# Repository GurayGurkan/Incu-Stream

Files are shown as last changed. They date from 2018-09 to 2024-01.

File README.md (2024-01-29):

# Incu-stream 1.0 (initial version)
**An Open-Hardware Live-Cell Imaging System Based on Inverted Bright-field Microscopy and Automated Mechanical Scanning for Real-Time and Long-Term Imaging of Microplates in Incubator**

This repository involves:
  - **CAD files**: AutoCAD drawings for housing of Incu-stream mechanical parts
  - **Schematics and pcb**: Circuit schematics and PCB layout files of Incu-stream control electronics.
  - **Software**: Involves C codes (for Atmega328) and Python codes (for Incu-stream user interface)
  - **Videos**: Demostration of device usage and example of a real-time recording acquired during C. Elegans movement.

For suggestions and questions, please e-mail to: **~~g.gurkan@iku.edu.tr~~**} (*not valid anymore. new e-mail: **guraygurkan@istanbul.edu.tr***)

Cheers!

Guray Gurkan

* **Please cite this repo as:** 

G. Gürkan and K. Gürkan, "*Incu-Stream 1.0: An Open-Hardware Live-Cell Imaging System Based on Inverted Bright-Field Microscopy and Automated Mechanical Scanning for Real-Time and Long-Term Imaging of Microplates in Incubator*," in **IEEE Access**, vol. 7, pp. 58764-58779, 2019. **doi: 10.1109/ACCESS.2019.2914958**

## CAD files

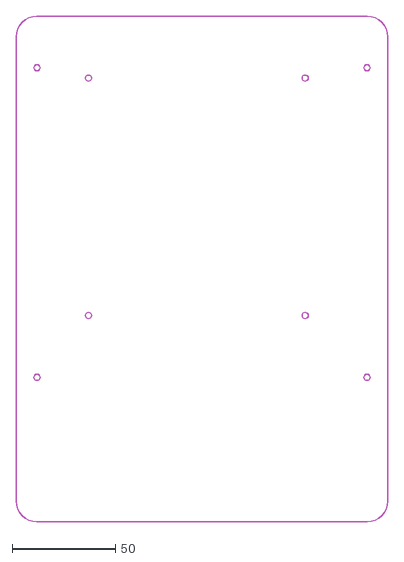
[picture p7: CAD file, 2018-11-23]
CAD_Files/IncuStreamCAD_IlluminationLayer.dxf
180.0 x 245.0

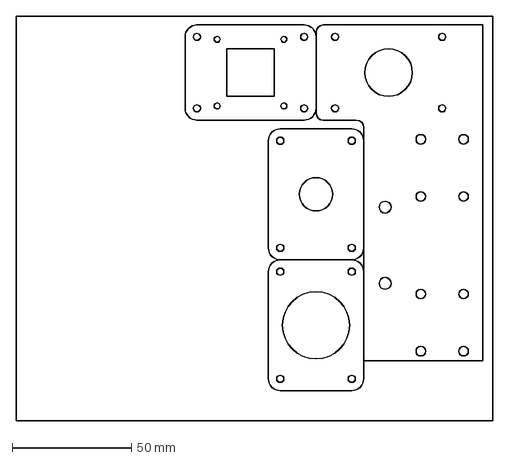
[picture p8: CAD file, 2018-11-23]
CAD_Files/IncuStreamCAD_XTray_Imager.dxf
200.0 x 170.0 mm

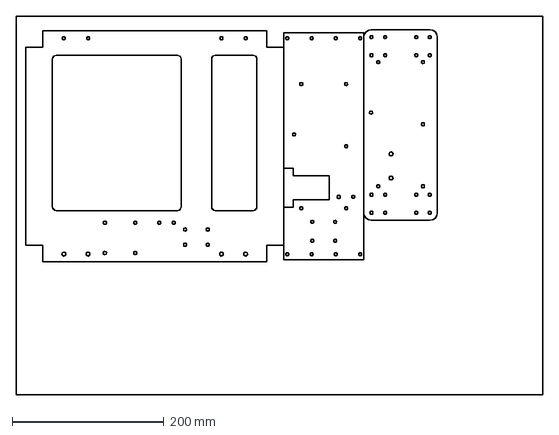
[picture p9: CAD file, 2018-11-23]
CAD_Files/IncuStreamCAD_Base_YTray.dxf
695.0 x 500.0 mm

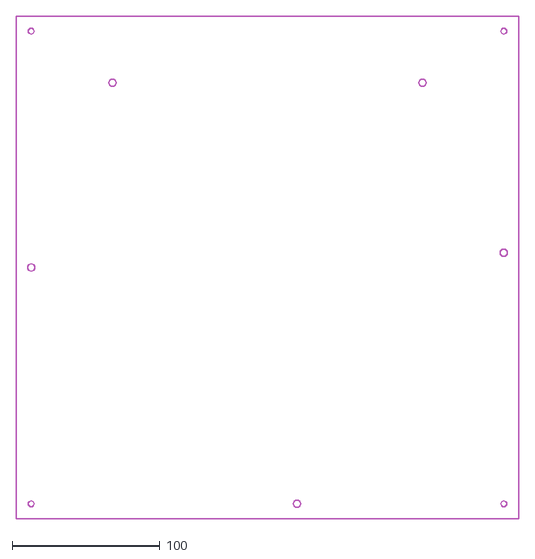
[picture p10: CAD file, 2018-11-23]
CAD_Files/IncuStreamCAD_BottomLayer.dxf
340.0 x 340.0

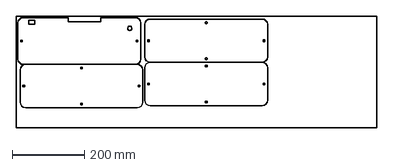
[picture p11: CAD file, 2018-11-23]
CAD_Files/IncuStreamCAD_SideLayers.dxf
1000.0 x 310.0 mm

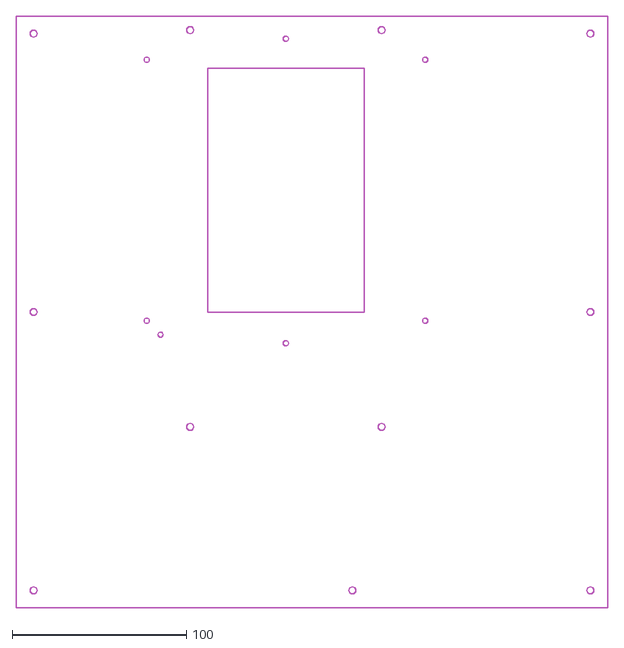
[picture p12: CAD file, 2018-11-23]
CAD_Files/IncuStreamCAD_TopLayer.dxf
340.0 x 340.0

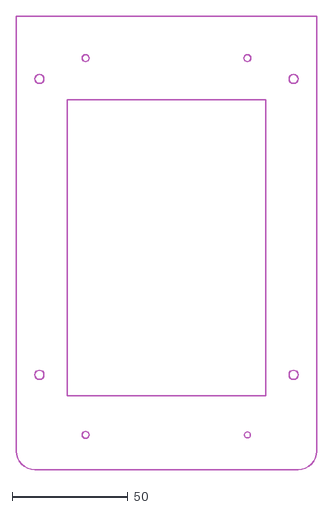
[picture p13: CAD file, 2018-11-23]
CAD_Files/IncuStreamCAD_PlateHolder.dxf
130.0 x 196.0

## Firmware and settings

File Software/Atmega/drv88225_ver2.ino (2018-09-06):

/*
Compatible with IncuStream Interface
This version has common DIR,STEP amd MODE pins for X,Y and Z (Lens) axis motors.

Developed by: Guray Gurkan, PhD
e-mail: guray_gurkan@yahoo.co.uk
*/

// 14.08.2018: Scanning Types 1,2 and 3 introduced
//  Type 1: Snake Like Scanning
//  Type 2: Single Y axis Reset, X axis bouncing
//  Type 3: Single Y axis Reset, Xaxis reset and bouncing

// StepXYZ() function changed for Long type
// Plate Offset, spacing are now in Long type
// 1/32 Microstepping is used for every movement
// XmYn command relies on "grid_selected" flag

/******************************
      DRV8825 Enable pins
******************************/
 
int Xen = 8;
int Yen = 9;
int Zen = 10;

/*****************************
      (Common) DRV8825
  Direction, Step and Mode pins
*****************************/
int XYZdir = 11; // 1->Reset Yonu, 0-> Uzaklasma
int XYZstep = 12;
int XYZSlowMode = 13;
int Positions[] = {0, 0, 0};

/*****************************
      More Externals
  X,Y Limit Switches,Buzzer, LED
*****************************/
int LEDPWM_pin = 3;
int BEEP_pin = 4;
int SWITCH_x_pin = 6;
int SWITCH_y_pin = 7 ;
int TRAY_pin = 5; // not used for current HW


/***********************************
  Well Plates vs. Steps required for TPP (1/32 Microstep)
***********************************/
unsigned long spacing[5] = {30016, 19968, 15200, 6400, 7200};
// In mm  {38, 25 , 19, ?, 9}; 

// A-1 Well Center Coordinates
unsigned long X_offset[5] = {0, 0, 49872, 0, 53664};
unsigned long Y_offset[5] = {3200, 3200, 14800, 3200, 14304};


/********************************
SUB- GRID CAMERA SHIFT steps for non-overlap
    DO NOT MODIFY!
*********************************/
unsigned long shiftX = 288;
unsigned long shiftY = 544;

 
// SUB-GRID scan row and column numbers
int rows;
int cols;

// LIVE VIEW PARAMETERS
int zstep = 320;
int zstep_fine = 40;
int xstep = 212;
int ystep = 272;

int resetsteps = 896; // in microstepping (1/32) drive mode

int deltaX;
int deltaY;

unsigned long  Xcurrent = 0;
unsigned long Ycurrent = 0;
unsigned long Zcurrent = 0;

#define SLOWMODE1 400
#define SLOWMODE2 20

int PFullDrive = 500 ; //Delay Microseconds 600 idi
int PSlowDrive = SLOWMODE2; //Delay Microseconds


/*
 *************************************
      BACKLASH CORRECTION
 *************************************
*/
byte lastdir[3] = {0, 0, 0}; // last directions
unsigned long lashes[3] = {0 , 0, 704};// 1/32 drive
int last_motor = 2;

boolean finished = false;
boolean started = false;
boolean grid_selected = false;

int plate_type;
int x_i, y_i;
int x_p, y_p;
int grid_count;
bool at_wellcenter = false;

void setup() {

  DDRB |= 0x3F;
  pinMode(BEEP_pin, OUTPUT);
  pinMode(LEDPWM_pin, OUTPUT);
  pinMode(SWITCH_x_pin, INPUT_PULLUP);//0 if at limit
  pinMode(SWITCH_y_pin, INPUT_PULLUP);

  digitalWrite(Xen, HIGH);
  digitalWrite(Yen, HIGH);
  digitalWrite(Zen, HIGH);

  delay(1000);

  delay(10);


  beep(BEEP_pin, 50, 1); // POWER ON ALERT


  // **************************************************************
  //               SETUP SERIAL and TRANSMIT DEVICE ACK
  // **************************************************************
  Serial.begin(9600);
  delay(100);

  Serial.print("INCU"); // Device ACK
  delay(100);
  beep(BEEP_pin, 400, 1);
  // **************************************************************
  //               END OF SERIAL SETUP and TRANSMIT DEVICE ACK
  // **************************************************************


  // **************************************************************
  //               SCAN DEFINITIONS: MANUAL ENTRIES
  // **************************************************************


  x_p = 0;
  y_p = 0;
  grid_count = 0;

  // **************************************************************
  //                    END OF SCAN PARAMETERS
  // **************************************************************


  // **************************************************************
  //                   LISTEN PORT and DETERMINE Plate-Type
  //            SETUP respect to input: "P" + id
  //  id=0, 6 Well
  //  id=1, 12 Well
  //  id=2, 24 Well
  //  id=3, 48 Well
  //  id=4, 96 Well
  // **************************************************************

  String sub = "";
  char val;
  while (!started)
  {
    if (wait_byte() == 'P')
    {
      val = wait_byte();
      if (isDigit(val))
      {
        sub += (char)val;
        plate_type = sub.toInt();
        sub = "";
        Serial.print("O");
        started = true;
        beep(BEEP_pin, 50, 1);

      }
    }
  }
  reset2origin(0);
  reset2origin(1);
  digitalWrite(LEDPWM_pin, 1);
  delay(1000);
  digitalWrite(LEDPWM_pin, 0);
  delay(1000);
  digitalWrite(LEDPWM_pin, 1);
  delay(1000);
  digitalWrite(LEDPWM_pin, 0);
  delay(1000);
  digitalWrite(LEDPWM_pin, 1);

}

void loop() {

  int task;
  if (!finished) {

    task = decodeMove();
    if (task == 1 && grid_selected == false) // 1: Goto "XnYm"
    {
      if (gotoWell())
      {
        Serial.print("O");
        grid_count++;
        delay(100);
      }
    }
    else if (task >= 2 && task < 6) // 2: Zp, Zn, xp, xn, yp, yn, zp, zn
    {
      Serial.print("O");
      delay(5);
      //;
      at_wellcenter = false;
    }
    else if (task == 6 && grid_selected == true) //capture grid
    {
      scanwell(plate_type);
      grid_count++;
    }
    else if (task == 7)
    {
      grid_selected = true;
      Serial.print("O");
    }
    else if (task == 8) // Light Control
    {
      Serial.print("O");
      delay(5);

    }
    else if (task == 0) //finish count
    {

      finished = true;
      digitalWrite(LEDPWM_pin, 0);
     delay(100);
      beep(BEEP_pin, 100, 2);
      reset2origin(0);
      reset2origin(1);
      asm volatile ("  jmp 0");
    }
    else if (task == -1)
    {
      Serial.print("U");
      delay(10);
    }

  }
  delay(50);
}

void stepXYZ(int motor_no, int yon, unsigned long adim, int kip)
{  unsigned long i;
  int Plength;

  // All OFF
  if (motor_no<2) // X or Y
  {
   if (motor_no != last_motor)

  {
    digitalWrite(Xen + last_motor, HIGH);// TURN OFF previous motor
    digitalWrite(Xen + motor_no, LOW);
    last_motor = motor_no;
  } 
  }
  else // Z
  {
    digitalWrite(Xen , HIGH);
    digitalWrite(Yen , HIGH);
    digitalWrite(Zen , LOW);
    last_motor=2;
  }
   
  digitalWrite(XYZSlowMode, kip);// kip = 0 -> Full drive, kip = 1 -> 1/32 drive

  digitalWrite(XYZdir, yon); // dir = 0 ?
  digitalWrite(Xen + motor_no, LOW);//ON
  delay(1);
  if (motor_no == 2)
    Plength = 200;
  else if (kip == 0)
    Plength = PFullDrive;
  else
    Plength = PSlowDrive;

  //Backlash Correction is applied to Z Axis if opposite direction is selected
  if (yon == intNOT( lastdir[motor_no]))
  {
    if ((kip == 1) & (motor_no==2))

    {
      digitalWrite(XYZdir, lastdir[motor_no]);// keep the last direction

      for (i = 0; i < 32; i++)
      {

        digitalWrite(XYZstep, HIGH);
        delayMicroseconds(Plength);
        digitalWrite(XYZstep, LOW);
        delayMicroseconds(Plength);
      }
      digitalWrite(XYZdir, yon);//
      delay(1);
      for (i = 0; i < (32 + lashes[motor_no]) ; i++)
      {

        digitalWrite(XYZstep, HIGH);
        delayMicroseconds(Plength);
        digitalWrite(XYZstep, LOW);
        delayMicroseconds(Plength);
      }

    }

  }

  lastdir[motor_no] = yon;

  for (i = 0; i < adim; i++)
  {

    digitalWrite(XYZstep, HIGH);
    delayMicroseconds(Plength);
    digitalWrite(XYZstep, LOW);
    delayMicroseconds(Plength);
  }
  if (yon == 0)
    Positions[motor_no] -= adim;
  else
    Positions[motor_no] += adim;
 if (motor_no==2)
   digitalWrite(Xen + motor_no, HIGH);//OFF if Z.
  delay(1);
}

void beep(int pin, int duration, int number)
{
  int c;
  for (c = 0; c < number; c++)
  {
    digitalWrite(pin, HIGH);
    delay(duration);
    digitalWrite(pin, LOW);
    delay(duration);
  }
}
void reset2origin(int axis)
{
  unsigned long i;
  i = 0;
  short j;
  int Plength = SLOWMODE2;//PFullDrive;
  digitalWrite(XYZSlowMode, 1);// kip = 0 -> Full drive, kip = 1 -> 1/32 drive
  digitalWrite(XYZdir, 1); // dir = 0 ?

  //ALL OFF, Release Motor Brakes
  digitalWrite(Xen, HIGH);
  digitalWrite(Yen, HIGH);
  digitalWrite(Zen, HIGH);
  
  digitalWrite(Xen + axis, LOW);//ON
  if (axis == 0)
  {
    while (digitalRead(SWITCH_x_pin))
    {
      digitalWrite(XYZstep, HIGH);
      delayMicroseconds(Plength);
      digitalWrite(XYZstep, LOW);
      delayMicroseconds(Plength);
      i++;
    }
  }
  else if (axis == 1)
  {
    while (digitalRead(SWITCH_y_pin))
    {
      digitalWrite(XYZstep, HIGH);
      delayMicroseconds(Plength);
      digitalWrite(XYZstep, LOW);
      delayMicroseconds(Plength);
      i++;
    }
  }
 
  digitalWrite(Xen + axis, HIGH);//OFF
  PSlowDrive = 60;
  last_motor = 2;// since x is next
  
  if (axis == 0)
  {
    stepXYZ(axis, 1, 1600, 1);
    stepXYZ(axis, 0, 1600 + resetsteps, 1);
  }
  else if (axis == 1)
  {
    stepXYZ(axis, 1, 64, 1);
    stepXYZ(axis, 0, 64 + resetsteps, 1);
  }
  PSlowDrive = SLOWMODE2;

  beep(BEEP_pin, 20, 5);
  lastdir[axis] = 0;

//ALL ON, Align for accuracy
  digitalWrite(Xen, LOW);
  digitalWrite(Yen, LOW);
  delay(10);
  digitalWrite(Xen, HIGH);//ALL OFF
  digitalWrite(Yen, HIGH);

 
}

int intNOT(int inp)
{
  if (inp > 0)
    return 0;
  else
    return 1;
}
char wait_byte()
{
  char inByte;
  do
  {
    delayMicroseconds(500);
  }
  while (Serial.available() == 0);
  inByte = Serial.read();
  return inByte;
}
char waitCommand()
{
  bool ok = false;
  char recbyte;

  do
  {
    recbyte = Serial.read();

    if ( recbyte == 'X' | recbyte == 'F' | recbyte == 'Z' | recbyte == 'x' | recbyte == 'y' | recbyte == 'z' | recbyte == 'G' | recbyte == 'r' | recbyte == 'i')
      ok = true;
  }
  while (!ok);
  return recbyte;//X, F, Z, x, y, z, G, r or i
}

int decodeMove()
{
  String sub = "";
  char x, option;
  option = waitCommand();
  if (option == 'X') {    // TASK 1: X-Y Movement
    //Serial.print("X");
    x = wait_byte();

    if (isDigit(x))
    {
      sub += (char)x;

      x_i = sub.toInt();
      sub = "";
    }

    if (wait_byte() == 'Y') { //may have two digits 1. or 12
      //Serial.print("Y");
      x = wait_byte();
      if (isDigit(x))
      {
        sub += (char)x;
        x = wait_byte();
        if (isDigit(x) && x > 0)
        {
          sub += (char)x;
          y_i = sub.toInt();
          sub = "";
        }
        else
        {
          y_i = sub.toInt();
          sub = "";
        }
      }
    }
    return 1;//X-Y Movement
  }
  else if (option == 'Z') // TASK 2: coarse focus
  {
    if (grid_count > 0)
    {
      x = wait_byte();
      beep(BEEP_pin, 20, 1);
      if (x == 'p')
      {
        stepXYZ(2, 1, zstep, 1);
        Zcurrent += zstep;
        return 2;
      }
      else if (x == 'n')
      {
        stepXYZ(2, 0, zstep, 1);
        Zcurrent -= zstep;
        return 2;
      }
    }
    else //grid_count = 0
      return -1;
  }
  else if (option == 'z') // TASK 5: fine focus
  {
    if (grid_count > 0)
    {
      x = wait_byte();
      beep(BEEP_pin, 20, 1);
      if (x == 'p') //Lens Up
      {
        stepXYZ(2, 1, zstep_fine, 1);
        Zcurrent += zstep_fine;
        return 5;
      }
      else if (x == 'n') // Lens Down
      {
        stepXYZ(2, 0, zstep_fine, 1);
        Zcurrent -= zstep_fine;
        return 5;
      }
    }
  }
  else if (option == 'x') // TASK 3: precise X
  {
    if (grid_count > 0)
    {
      x = wait_byte();
      beep(BEEP_pin, 50, 2);
      if (x == 'p')
      {
        stepXYZ(0, 1, xstep, 1);
        //Xcurrent += xstep;
        deltaX += xstep;
        return 3;
      }


      else if (x == 'n')
      {
        stepXYZ(0, 0, xstep, 1);
        //Xcurrent -= xstep;
        deltaX -= xstep;

        return 3;
      }
    }

    else //grid_count = 0
    {
      return -1;
    }
  }
  else if (option == 'y') // TASK 4: precise Y
  {
    if (grid_count > 0)
    {

      x = wait_byte();
      beep(BEEP_pin, 50, 2);
      if (x == 'p')
      {
        stepXYZ(1, 0, ystep, 1);
        //Ycurrent += ystep;
        deltaY += ystep;

        return 4;
      }
      else if (x == 'n')
      {
        stepXYZ(1, 1, ystep, 1);
        //Ycurrent -= ystep;
        deltaY -= ystep;

        return 4;
      }
    }

    else //grid_count = 0
      return -1;
  }

  else if (option == 'G')
  {
    return 6;
  }
  else if (option == 'r') { // TASK 7: Grid Selection

    x = wait_byte();
    sub = "";
    if (isDigit(x))
    {
      sub += (char)x;
      x = wait_byte();
      if (isDigit(x) && x > 0)
      {
        sub += (char)x;
        rows = sub.toInt();
        sub = "";
      }
      else
      {
        rows = sub.toInt();
        sub = "";
      }
    }


    if (wait_byte() == 'c') { //may have two digits 1. or 12
      //Serial.print("Y");
      x = wait_byte();
      if (isDigit(x))
      {
        sub += (char)x;
        x = wait_byte();
        if (isDigit(x) && x > 0)
        {
          sub += (char)x;
          cols = sub.toInt();
          sub = "";
        }
        else
        {
          cols = sub.toInt();
          sub = "";
        }
      }
    }

    return 7;
  }

  else if (option == 'i') // TASK 8 : LED CONTROL
  {
    if (grid_count > 0)
    {

      x = wait_byte();
      beep(BEEP_pin, 50, 2);
      if (x == 'p')
      {
        digitalWrite(LEDPWM_pin, 1);
        return 8;
      }
      else if (x == 'n')
      {

        digitalWrite(LEDPWM_pin, 0);
        return 8;
      }

    }

    else //grid_count = 0
      return -1;
  }
  else // "F"     // TASK 0: Finish/Reset
  {

    return 0;
  }
}

bool gotoWell() //requires global "count"
{

  unsigned long  x_move, y_move;
  x_move = 0;
  y_move = 0;
  unsigned long FastTrack;
  FastTrack = 1500; // 6 cm
  PSlowDrive = SLOWMODE2;
  if (grid_count == 0)
  {

    stepXYZ(0, 0, X_offset[plate_type] , 1);
    stepXYZ(1, 0, Y_offset[plate_type], 1);
    Xcurrent = 67200 - X_offset[plate_type];
    Ycurrent += Y_offset[plate_type];

    x_move = (x_i - 1) * spacing[plate_type];
    stepXYZ(0, 1, x_move, 1);
    Xcurrent += x_move;

    y_move = (y_i - 1) * spacing[plate_type];
    delay(1);
    stepXYZ(1, 0, y_move, 1);
    Ycurrent += y_move;

    x_p = x_i;
    y_p = y_i;
  }
  else
  {
    center_camera();

    if (y_i >= y_p) // move opposite to origin Y
    {
      y_move = (y_i - y_p) * spacing[plate_type];
      stepXYZ(1, 0, y_move, 1);
      Ycurrent += y_move;
    }
    else // move towards origin Y
    {
      /* ******* 14.08.2018 *******
        // To prevent backlash, do not go towards -y, reset and then go towards +y.
        // The below line is cancelled
        // y_move = (y_p - y_i) * spacing[plate_type];
      */
      reset2origin(1);
      delay(2);
      y_move = (y_i - 1) * spacing[plate_type] + Y_offset[plate_type];
      stepXYZ(1, 0, y_move, 1);
      Ycurrent += y_move ;
    }
    delay(1);
    if (x_i >= x_p)
    {
      x_move = (x_i - x_p) * spacing[plate_type];
      stepXYZ(0, 1, x_move, 1);

      Xcurrent += x_move;
    }
    else
    {
      x_move = (x_p - x_i) * spacing[plate_type];
      stepXYZ(0, 0, x_move, 1);
      Xcurrent -= x_move;
    }
    delay(1);
    x_p = x_i;
    y_p = y_i;
  }

  at_wellcenter = true;
  PSlowDrive = SLOWMODE1;
  return true;
}

void center_camera()
{
  if (deltaX > 0)
    stepXYZ(0, 0, deltaX, 1);
  else if (deltaX < 0)
    stepXYZ(0, 1, -deltaX, 1);

  if (deltaY > 0)
    stepXYZ(1, 1, deltaY, 1);
  else if (deltaY < 0)
    stepXYZ(1, 0, -deltaY, 1);
  deltaX = 0;
  deltaY = 0;
}

void scanwell(int type)
{
  digitalWrite(LEDPWM_pin, 1);
 
  //FOVx = 156 adim
  //FOVy = 296 adim

  int Nx, Ny, dirx, diry, count_x, count_y;
  unsigned long dx, dy;
  unsigned long x_min, y_min;
  bool scanOK = false;
  int scanMode = 1;

  count_x = 1;
  count_y = 1;
  // goto top-left
  Nx = rows;//[type];// global arrays
  Ny = cols;//[type];

  dx = ((Nx - 1) / 2) * shiftX;
  dy = ((Ny - 1) / 2) * shiftY;

  //Reset X and Y
  reset2origin(0);
  delay(2);
  reset2origin(1);
  delay(2);
  //Go to MinY

  y_min = Y_offset[type] - dy + (y_i - 1) * spacing[type];
  PSlowDrive = SLOWMODE2;
  stepXYZ(1, 0, y_min , 1);
  PSlowDrive = SLOWMODE1;

  //Go to MinX

  x_min = X_offset[type] - (dx + ((x_i - 1) * spacing[type]));
  /*
                  PRINT VALUES FOR DEBUGGING!
  */

  //  Serial.print("Xmin,Ymin: ");
  //  Serial.print(x_min);
  //  Serial.print(",");
  //  Serial.println(y_min);
  // **************************

  PSlowDrive = SLOWMODE2;
  stepXYZ(0, 0, x_min , 1);
  PSlowDrive = SLOWMODE1;


  while (!scanOK)
  {
    if (count_x < Nx + 1)
    {
      if (count_x > 1)
      {
        stepXYZ(0, 0, shiftX, scanMode);
      }
      delay(200);
      Serial.print("C");
      do;
      while (!(wait_byte() == 'O'));
      count_x++;
      delay(10);
    }
    else
    {


      if (count_y < Ny )
      {
        // Type 2 Scan
        PSlowDrive = SLOWMODE1;
        stepXYZ(1, 0, shiftY , 1);
        delay(1);
        //Reset X
        reset2origin(0);
        PSlowDrive = SLOWMODE2;
        stepXYZ(0, 0, x_min , 1);
        PSlowDrive = SLOWMODE1;
        count_x = 1;

        count_y++;
        delay(1);
      }
      else
      {

        scanOK = true;
        Serial.println("W");
        digitalWrite(LEDPWM_pin, 0);


      }
    }
  }
}

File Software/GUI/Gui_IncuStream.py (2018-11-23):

# -*- coding: utf-8 -*-

# Form implementation generated from reading ui file 'Gui_IncuStream.ui'
#
# Created: Fri Nov 02 08:50:56 2018
#      by: PyQt4 UI code generator 4.11.3
#
# WARNING! All changes made in this file will be lost!

from PyQt4 import QtCore, QtGui

try:
    _fromUtf8 = QtCore.QString.fromUtf8
except AttributeError:
    def _fromUtf8(s):
        return s

try:
    _encoding = QtGui.QApplication.UnicodeUTF8
    def _translate(context, text, disambig):
        return QtGui.QApplication.translate(context, text, disambig, _encoding)
except AttributeError:
    def _translate(context, text, disambig):
        return QtGui.QApplication.translate(context, text, disambig)

class Ui_MainWindow(object):
    def setupUi(self, MainWindow):
        MainWindow.setObjectName(_fromUtf8("MainWindow"))
        MainWindow.resize(994, 700)
        sizePolicy = QtGui.QSizePolicy(QtGui.QSizePolicy.Preferred, QtGui.QSizePolicy.Preferred)
        sizePolicy.setHorizontalStretch(0)
        sizePolicy.setVerticalStretch(0)
        sizePolicy.setHeightForWidth(MainWindow.sizePolicy().hasHeightForWidth())
        MainWindow.setSizePolicy(sizePolicy)
        MainWindow.setMinimumSize(QtCore.QSize(940, 700))
        MainWindow.setMaximumSize(QtCore.QSize(1920, 1080))
        icon = QtGui.QIcon()
        icon.addPixmap(QtGui.QPixmap(_fromUtf8(":/Icons/images/Start.ico")), QtGui.QIcon.Normal, QtGui.QIcon.Off)
        MainWindow.setWindowIcon(icon)
        MainWindow.setWindowOpacity(1.0)
        self.centralwidget = QtGui.QWidget(MainWindow)
        self.centralwidget.setObjectName(_fromUtf8("centralwidget"))
        self.tabWidget = QtGui.QTabWidget(self.centralwidget)
        self.tabWidget.setEnabled(True)
        self.tabWidget.setGeometry(QtCore.QRect(30, 30, 951, 571))
        sizePolicy = QtGui.QSizePolicy(QtGui.QSizePolicy.MinimumExpanding, QtGui.QSizePolicy.MinimumExpanding)
        sizePolicy.setHorizontalStretch(0)
        sizePolicy.setVerticalStretch(0)
        sizePolicy.setHeightForWidth(self.tabWidget.sizePolicy().hasHeightForWidth())
        self.tabWidget.setSizePolicy(sizePolicy)
        self.tabWidget.setMaximumSize(QtCore.QSize(1000, 600))
        self.tabWidget.setBaseSize(QtCore.QSize(0, 0))
        font = QtGui.QFont()
        font.setFamily(_fromUtf8("Consolas"))
        font.setBold(False)
        font.setWeight(50)
        self.tabWidget.setFont(font)
        self.tabWidget.setAutoFillBackground(False)
        self.tabWidget.setTabPosition(QtGui.QTabWidget.North)
        self.tabWidget.setTabShape(QtGui.QTabWidget.Rounded)
        self.tabWidget.setElideMode(QtCore.Qt.ElideMiddle)
        self.tabWidget.setUsesScrollButtons(False)
        self.tabWidget.setDocumentMode(True)
        self.tabWidget.setTabsClosable(False)
        self.tabWidget.setObjectName(_fromUtf8("tabWidget"))
        self.tab_Setup = QtGui.QWidget()
        self.tab_Setup.setObjectName(_fromUtf8("tab_Setup"))
        self.comboBox_ports = QtGui.QComboBox(self.tab_Setup)
        self.comboBox_ports.setEnabled(False)
        self.comboBox_ports.setGeometry(QtCore.QRect(680, 370, 101, 20))
        font = QtGui.QFont()
        font.setBold(False)
        font.setWeight(50)
        self.comboBox_ports.setFont(font)
        self.comboBox_ports.setObjectName(_fromUtf8("comboBox_ports"))
        self.groupBox_Setup = QtGui.QGroupBox(self.tab_Setup)
        self.groupBox_Setup.setGeometry(QtCore.QRect(20, 20, 631, 333))
        self.groupBox_Setup.setFlat(False)
        self.groupBox_Setup.setObjectName(_fromUtf8("groupBox_Setup"))
        self.grids = QtGui.QLabel(self.groupBox_Setup)
        self.grids.setGeometry(QtCore.QRect(297, 18, 300, 300))
        sizePolicy = QtGui.QSizePolicy(QtGui.QSizePolicy.Fixed, QtGui.QSizePolicy.Fixed)
        sizePolicy.setHorizontalStretch(0)
        sizePolicy.setVerticalStretch(0)
        sizePolicy.setHeightForWidth(self.grids.sizePolicy().hasHeightForWidth())
        self.grids.setSizePolicy(sizePolicy)
        self.grids.setMinimumSize(QtCore.QSize(300, 300))
        self.grids.setMaximumSize(QtCore.QSize(300, 300))
        self.grids.setText(_fromUtf8(""))
        self.grids.setObjectName(_fromUtf8("grids"))
        self.groupBox_2 = QtGui.QGroupBox(self.groupBox_Setup)
        self.groupBox_2.setGeometry(QtCore.QRect(28, 23, 250, 50))
        sizePolicy = QtGui.QSizePolicy(QtGui.QSizePolicy.Fixed, QtGui.QSizePolicy.Fixed)
        sizePolicy.setHorizontalStretch(0)
        sizePolicy.setVerticalStretch(0)
        sizePolicy.setHeightForWidth(self.groupBox_2.sizePolicy().hasHeightForWidth())
        self.groupBox_2.setSizePolicy(sizePolicy)
        self.groupBox_2.setMinimumSize(QtCore.QSize(250, 50))
        self.groupBox_2.setMaximumSize(QtCore.QSize(200, 50))
        font = QtGui.QFont()
        font.setFamily(_fromUtf8("Consolas"))
        font.setBold(False)
        font.setWeight(50)
        self.groupBox_2.setFont(font)
        self.groupBox_2.setAlignment(QtCore.Qt.AlignLeading|QtCore.Qt.AlignLeft|QtCore.Qt.AlignTop)
        self.groupBox_2.setFlat(False)
        self.groupBox_2.setObjectName(_fromUtf8("groupBox_2"))
        self.horizontalLayout_2 = QtGui.QHBoxLayout(self.groupBox_2)
        self.horizontalLayout_2.setObjectName(_fromUtf8("horizontalLayout_2"))
        self.platetype = QtGui.QComboBox(self.groupBox_2)
        self.platetype.setEditable(False)
        self.platetype.setMaxVisibleItems(5)
        self.platetype.setModelColumn(0)
        self.platetype.setObjectName(_fromUtf8("platetype"))
        self.horizontalLayout_2.addWidget(self.platetype)
        self.Group_subgrid = QtGui.QGroupBox(self.groupBox_Setup)
        self.Group_subgrid.setGeometry(QtCore.QRect(30, 80, 250, 200))
        sizePolicy = QtGui.QSizePolicy(QtGui.QSizePolicy.Fixed, QtGui.QSizePolicy.Fixed)
        sizePolicy.setHorizontalStretch(0)
        sizePolicy.setVerticalStretch(0)
        sizePolicy.setHeightForWidth(self.Group_subgrid.sizePolicy().hasHeightForWidth())
        self.Group_subgrid.setSizePolicy(sizePolicy)
        self.Group_subgrid.setMinimumSize(QtCore.QSize(250, 200))
        self.Group_subgrid.setMaximumSize(QtCore.QSize(200, 150))
        self.Group_subgrid.setCheckable(True)
        self.Group_subgrid.setChecked(False)
        self.Group_subgrid.setObjectName(_fromUtf8("Group_subgrid"))
        self.gridLayout_7 = QtGui.QGridLayout(self.Group_subgrid)
        self.gridLayout_7.setObjectName(_fromUtf8("gridLayout_7"))
        self.combo_decimation = QtGui.QComboBox(self.Group_subgrid)
        self.combo_decimation.setObjectName(_fromUtf8("combo_decimation"))
        self.combo_decimation.addItem(_fromUtf8(""))
        self.combo_decimation.addItem(_fromUtf8(""))
        self.combo_decimation.addItem(_fromUtf8(""))
        self.combo_decimation.addItem(_fromUtf8(""))
        self.combo_decimation.addItem(_fromUtf8(""))
        self.gridLayout_7.addWidget(self.combo_decimation, 3, 1, 1, 1)
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

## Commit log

2018-09-03 New Debugging
    - Status E-mail is now optional, no errors if empty username-password or server
    [B_VER23_IncuStream.py]
2018-11-23 Final Changes
    [IncuStreamCAD_Base_YTray.dxf, IncuStreamCAD_BottomLayer.dxf, IncuStreamCAD_IlluminationLayer.dxf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]
